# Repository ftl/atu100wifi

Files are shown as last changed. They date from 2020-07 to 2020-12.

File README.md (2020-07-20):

# atu100wifi

This is a little extension device for David Fainitski's [ATU-100](https://github.com/Dfinitski/N7DDC-ATU-100-mini-and-extended-boards) antenna tuner. It adds connectivity though wifi to use the tuner in a remote setup. The software publishes all measurement data using MQTT and accepts remote commands through another MQTT topic.

The device replaces the tuner's display. It communicates with the ATU-100 through it's I2C bus to grasp all the measurement data. An Arduino Nano acts as I2C slave, listening with the display's address, and interpreting the rendering commands coming from the ATU-100. The Nano sends the display content to an ESP8266 [WeMos D1 mini](https://www.wemos.cc/en/latest/d1/d1_mini.html), where the data is parsed, packed into a JSON object and published to a MQTT topic.

This project uses PlatformIO to build the software for the MCUs.

## Disclaimer
I develop this device for myself and just for fun in my free time. If you find it useful, I'm happy to hear about that. If you have trouble using it, you have all the source code to fix the problem yourself (although pull requests are welcome).

I am not liable for whatever happens to you by building or using this device. Do this on your own risk!

## License
This tool is published under the [MIT License](https://www.tldrlegal.com/l/mit).

Copyright [Florian Thienel](http://thecodingflow.com/)

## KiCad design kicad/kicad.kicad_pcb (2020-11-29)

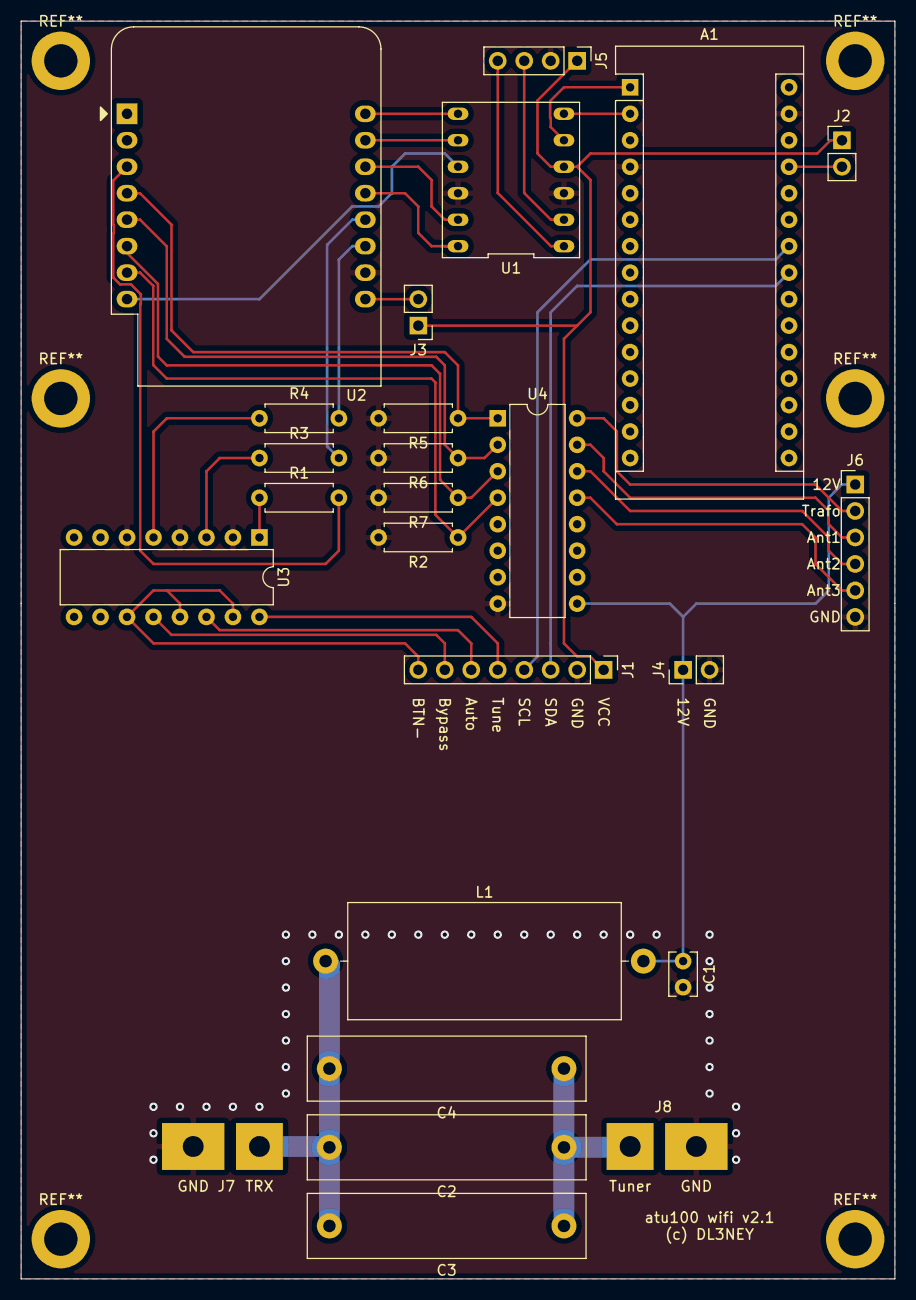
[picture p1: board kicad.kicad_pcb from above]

Board: 2 copper layers, 83.8 x 120.7 mm, 25 parts (0 on the bottom side), 36 nets.

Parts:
A1: Arduino_Nano_v3.x; Arduino_Nano
C1: 100n; C_Rect_L4.0mm_W2.5mm_P2.50mm
C2, C3, C4: 10n; C_Rect_L26.5mm_W6.0mm_P22.50mm_MKS4
J1: ATU100; PinHeader_1x08_P2.54mm_Vertical
J2, J3: Conn_01x02_Male; PinHeader_1x02_P2.54mm_Vertical
J4: ATU100_12V; PinHeader_1x02_P2.54mm_Vertical
J5: Display/I2C; PinHeader_1x04_P2.54mm_Vertical
J6: Ant Switch; PinHeader_1x06_P2.54mm_Vertical
J7: TRX; SolderWirePad_1x02_P7.62mm_Drill2mm
J8: Tuner; SolderWirePad_1x02_P7.62mm_Drill2mm
L1: 1m; L_Axial_L26.0mm_D11.0mm_P30.48mm_Horizontal_Fastron_77A
R1, R3, R4: 470; R_Axial_DIN0207_L6.3mm_D2.5mm_P7.62mm_Horizontal
R2, R5, R6, R7: 10k; R_Axial_DIN0207_L6.3mm_D2.5mm_P7.62mm_Horizontal
U1: 4Bit_China_Level_Shifter
U2: WeMos_D1_mini; WEMOS_D1_mini_light
U3: LTV-847; DIP-16_W7.62mm
U4: ULN2004A; DIP-16_W7.62mm

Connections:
+3V3: U1.9, U2.8
+12V: C1.1, J4.1, J6.1, L1.2, U4.9
Ant1: J6.3, U4.15
Ant2: J6.4, U4.14
Ant3: J6.5, U4.13
BTN-: J1.8, U3.11, U3.13, U3.15
BTNAuto+: J1.6, U3.14
BTNByp+: J1.7, U3.12
BTNTune+: J1.5, U3.16
D0: R1.2, U2.3
D1: U1.11, U2.14
D2: U1.12, U2.13
D3: R3.2, U2.12
D4: R4.2, U2.11
D5: R5.1, U2.4, U4.1
D6: R6.1, U2.5, U4.2
D7: R7.1, U2.6, U4.3
D8: R2.1, U2.7, U4.4
GND: A1.4, A1.29, C1.2, J1.2, J4.2, J5.2, J6.6, J7.2, J8.2, R2.2, R5.2, R6.2, R7.2, U1.3, U1.10, U2.10, U3.2, U3.4, U3.6, U4.8
unnamed: A1.1, U1.5
unnamed: A1.2, U1.6
unnamed: A1.27, J2.2
unnamed: C2.1, C3.1, C4.1, J8.1
unnamed: C2.2, C3.2, C4.2, J7.1, L1.1
unnamed: J3.2, U2.9
unnamed: R1.1, U3.1
unnamed: R3.1, U3.3
unnamed: R4.1, U3.5
unnamed: U1.7, U2.16
unnamed: U1.8, U2.15
SCL: A1.24, J1.4
SCL2: J5.4, U1.1
SDA: A1.23, J1.3
SDA2: J5.3, U1.2
Trafo: J6.2, U4.16
VCC: J1.1, J2.1, J3.1, J5.1, U1.4

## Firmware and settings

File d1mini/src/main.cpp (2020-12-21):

/*
  This piece of software receives the display content of the ATU-100 on the serial interface
  and publishes the measurement data via MQTT.

  The following topics are used to publish data:
  * MQTT_DATA_TOPIC: all the measurement data as JSON object, on every change
  * MQTT_RSSI_TOPIC: the current RSSI of the wifi, every 10 seconds
  * MQTT_WILL_TOPIC: "true" as soon as the MQTT connection is established, "false" as last will

  The software also subscribes to MQTT_CMD_TOPIC in order to receive commands:
  * "1" will push the TUNE button for 500ms
  * "2" will push the AUTO button for 500ms
  * "3" will push the BYPASS button for 500ms
  * "4" will turn on the TRAFO relay
  * "5" will turn off the TRAFO relay
  * "6" will turn on the ANT1 relay
  * "7" will turn on the ANT2 relay
  * "8" will turn on the ANT3 relay
  
  All configuration data is defined in the file include/config.h. Create it from include/config-template.
*/

#include <Arduino.h>
#include <ESP8266WiFi.h>
#include <WiFiClient.h>
#include <PubSubClient.h>
#include "config.h" // create this header from include/config-template.h and fill it with all your configuration data

#define TUNE_BTN D0
#define AUTO_BTN D3
#define BYPASS_BTN D4 // this is the LED_BUILTIN and we need it to indicate the status of the WIFI connection

#define TRAFO_RLY D5
#define ANT1_RLY D6
#define ANT2_RLY D7
#define ANT3_RLY D8

void onMQTTMessage(char*, byte*, unsigned int);

WiFiClient client;
WiFiClient wifi;
PubSubClient mqtt(wifi);
bool wifiConnected = false;
bool mqttConnected = false;

long lastBeat = 0L;

String displayContent;
uint8_t currentIndex = 0;

void handleDisplayUpdate();

void blinkLED(int on, int off) {
  #ifdef WIFI_LED
  digitalWrite(LED_BUILTIN, LOW);
  delay(on);
  digitalWrite(LED_BUILTIN, HIGH);
  delay(off);
  #endif
}

void publishString(String topic, String value) {
  char topicBuf[topic.length() + 1];
  topic.toCharArray(topicBuf, topic.length() + 1);

  char valueBuf[value.length() + 1];
  value.toCharArray(valueBuf, value.length() + 1);
    
  mqtt.publish(topicBuf, valueBuf, true);  
}

void publishInt(String topic, int value) {
  String str = String(value);
  publishString(topic, str);
}

void heartbeat(int seconds) {
  if (!mqtt.connected()) return;

  long now = millis();
  if (now - lastBeat < seconds * 1000) return;
  lastBeat = now;

  String rssi = String(WiFi.RSSI());

  publishString(MQTT_RSSI_TOPIC, rssi);
}

void setupOutput(uint8_t pin) {
  pinMode(pin, OUTPUT);
  digitalWrite(pin, LOW);
}

void setup() {
  pinMode(LED_BUILTIN, OUTPUT);
  setupOutput(TUNE_BTN);
  setupOutput(AUTO_BTN);
  setupOutput(TRAFO_RLY);
  setupOutput(ANT1_RLY);
  setupOutput(ANT2_RLY);
  setupOutput(ANT3_RLY);

  digitalWrite(ANT1_RLY, HIGH);

  Serial.begin(9600);
}

void loop() {
  if (WiFi.status() != WL_CONNECTED) {
    Serial.println("No WiFi connection");
    wifiConnected = false;
    WiFi.hostname(WIFI_HOSTNAME);
    WiFi.begin(WIFI_SSID, WIFI_PASSPHRASE);
    for (int i = 0; i < 10 && WiFi.status() != WL_CONNECTED; i++) {
      blinkLED(50, 450);
    }

    if (WiFi.status() == WL_CONNECTED) {
      Serial.println("WiFi connected");
      wifiConnected = true;
      mqtt.setServer(MQTT_HOST, MQTT_PORT);
    }
    return;
  }

  if (!mqttConnected) {
    Serial.println("No MQTT connection");
    blinkLED(50, 50);
    blinkLED(50, 350);
    mqtt.setCallback(onMQTTMessage);
    mqttConnected = mqtt.connect(MQTT_CLIENT_ID, MQTT_USER, MQTT_PASSWORD, MQTT_WILL_TOPIC, 2, true, "false");
    if (mqttConnected) {
      Serial.println("MQTT connected");
      publishString(MQTT_WILL_TOPIC, "true");
      mqtt.subscribe(MQTT_CMD_TOPIC);
    }
    return;
  }

  #ifdef WIFI_LED
  digitalWrite(LED_BUILTIN, LOW);
  #endif

  // handle the input from the Arduino Nano
  if (Serial.available()) {
      char c = Serial.read();
      if (c == 0x0A) {
          handleDisplayUpdate();
          currentIndex = 0;
          displayContent = "";
      } else if (c < 0x20) {
          // ignore control characters
      } else {
          displayContent += c;
      }
  }

  heartbeat(10);

  mqtt.loop();
}

void handleDisplayUpdate() {
  if (displayContent.substring(0, 4) != "PWR=") {
    Serial.println("wrong line format");
    return;
  }

  String pwrIn = displayContent.substring(4, 7);
  pwrIn.trim();
  bool autoMode = (displayContent.charAt(8) == '.');
  bool txing = (displayContent.charAt(11) == '=') || ((displayContent.charAt(76) == '='));
  bool tuning = displayContent.substring(68, 72) == "TUNE";
  bool resetting = displayContent.substring(64, 69) == "RESET";

  String swr = "";
  if (displayContent.substring(64, 68) == "SWR=" && !tuning) {
    swr = displayContent.substring(68, 72);
  }

  String pwrOut = "";
  String efficiency = "";
  bool lcNetwork = false;
  String inductance = "";
  String capacitance = "";
  if (txing) {
    pwrOut = displayContent.substring(12, 15);
    efficiency = displayContent.substring(77, 79);
  } else if (displayContent.charAt(9) == 'L') {
    lcNetwork = true;
    inductance = displayContent.substring(11, 15);
    capacitance = displayContent.substring(75, 79);
    capacitance.trim();
  } else {
    lcNetwork = false;
    inductance = displayContent.substring(75, 79);
    capacitance = displayContent.substring(11, 15);
    capacitance.trim();
  }

  String json = "{";
  if (tuning) {
    json += "\"tuning\":true,";
  } else {
    json += "\"tuning\":false,";
  }
  if (resetting) {
    json += "\"resetting\":true,";
  } else {
    json += "\"resetting\":false,";
  }
  if (autoMode) {
    json += "\"auto_mode\":true,";
  } else {
    json += "\"auto_mode\":false,";
  }
  json += "\"pwr_in\":" + pwrIn + ",";
  if (txing) {
    json += "\"txing\":true,";
    json += "\"pwr_out\":" + pwrOut + ",";
    json += "\"efficiency\":" + efficiency + ",";
  } else {
    json += "\"txing\":false,";
    json += "\"pwr_out\":0,";
    json += "\"efficiency\":0,";
  }
  if (swr != "") {
    json += "\"swr\":" + swr + ",";
  } else {
    json += "\"swr\":0,";
  }
  if (lcNetwork) {
    json += "\"lc_network\":true";
  } else {
    json += "\"lc_network\":false";
  }
  if (inductance != "" && capacitance != "") {
    json += ",\"inductance\":" + inductance + ",";
    json += "\"capacitance\":" + capacitance;
  }
  json += "}";

  publishString(MQTT_DATA_TOPIC, json);
}

void pressButton(uint8_t pin) {
  Serial.print("press button ");
  Serial.println(pin);
  digitalWrite(pin, HIGH);
  delay(500);
  digitalWrite(pin, LOW);
}

void switchTrafo(uint8_t val) {
  Serial.print("switch trafo ");
  Serial.println(val);
  digitalWrite(TRAFO_RLY, val);
  publishInt(MQTT_TRAFO_RELAY_TOPIC, val);
}

void selectAntenna(uint8_t antenna) {
  Serial.print("select antenna ");
  Serial.println(antenna);
  switch (antenna) {
  case 1:
    digitalWrite(ANT1_RLY, HIGH);
    digitalWrite(ANT2_RLY, LOW);
    digitalWrite(ANT3_RLY, LOW);
    break;
  case 2:
    digitalWrite(ANT1_RLY, LOW);
    digitalWrite(ANT2_RLY, HIGH);
    digitalWrite(ANT3_RLY, LOW);
    break;
  case 3:
    digitalWrite(ANT1_RLY, LOW);
    digitalWrite(ANT2_RLY, LOW);
    digitalWrite(ANT3_RLY, HIGH);
    break;
  default:
    antenna = 1;
    digitalWrite(ANT1_RLY, HIGH);
    digitalWrite(ANT2_RLY, LOW);
    digitalWrite(ANT3_RLY, LOW);
  }
  publishInt(MQTT_ANT1_RELAY_TOPIC, (antenna == 1));
  publishInt(MQTT_ANT2_RELAY_TOPIC, (antenna == 2));
  publishInt(MQTT_ANT3_RELAY_TOPIC, (antenna == 3));
}

void onMQTTMessage(char* topic, byte* payload, unsigned int length) {
  if (length == 0) {
    return;
  }
  char c = (char)payload[0];
  switch (c) {
  case '1':
    pressButton(TUNE_BTN);
    break;
  case '2':
    pressButton(TUNE_BTN);
    break;
  case '3':
    pressButton(TUNE_BTN);
    break;
  case '4':
    switchTrafo(HIGH);
    break;
  case '5':
    switchTrafo(LOW);
    break;
  case '6':
    selectAntenna(1);
    break;
  case '7':
    selectAntenna(2);
    break;
  case '8':
    selectAntenna(3);
    break;
  }
}

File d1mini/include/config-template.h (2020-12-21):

/*
    This header contains all the configuration data.
*/

#define WIFI_SSID "myssid"
#define WIFI_PASSPHRASE "mysecretpassphrase"
#define WIFI_HOSTNAME "myatu100"
// uncomment to use the built-in LED to indicate the WIFI status
// ATTENTION: this collides with the support for the BYPASS button. 
// If you use WIFI_LED, do NOT connect the BYPASS button!
// #define WIFI_LED

#define MQTT_HOST "192.168.1.1"
#define MQTT_PORT 1883
#define MQTT_CLIENT_ID "atu100"
#define MQTT_USER ""
#define MQTT_PASSWORD ""
#define MQTT_DATA_TOPIC "hamradio/atu100/data"
#define MQTT_RSSI_TOPIC "hamradio/atu100/rssi"
#define MQTT_WILL_TOPIC "hamradio/atu100/alive"
#define MQTT_CMD_TOPIC "hamradio/atu100/cmd"
#define MQTT_TRAFO_RELAY_TOPIC "afu/atu100/relays/trafo"
#define MQTT_ANT1_RELAY_TOPIC "afu/atu100/relays/ant1"
#define MQTT_ANT2_RELAY_TOPIC "afu/atu100/relays/ant2"
#define MQTT_ANT3_RELAY_TOPIC "afu/atu100/relays/ant3"

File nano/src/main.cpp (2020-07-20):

/*
  This piece of software acts as like a HD44780 LCD on the I2C bus. 
  
  The Nano receives the HD44780 instructions as an I2C slave using the default pins A4 (SDA) and A5 (SCL).
  It applies the instructions to a local representation of the display content. On each change
  of the display content it sends the whole display content (80 characters) out via the serial interface (TX pin).

  More details about the HD44780 LCD instruction set: 
  * https://mil.ufl.edu/3744/docs/lcdmanual/commands.html
  * https://www.sparkfun.com/datasheets/LCD/HD44780.pdf

  Only instructions that affect the display content are implemented (no read, no character generation).
*/

#include <Arduino.h>
#include <Wire.h>

#define LCD_ADDRESS 0x27
#define LCD_LENGTH 80
#define DDRAM 0
#define CGRAM 1
#define PUBLISH_THRESHOLD 100

bool dirty = false;
unsigned long cleanTime = 0;
bool published = true;

char ddram[LCD_LENGTH];
bool ramIndex = DDRAM;
uint8_t currentAddress = 0;
bool entryModeIncrement = true;
bool entryModeShift = false;

void onReceive(int);
void handleCommand(bool, bool, uint8_t);
void clearDisplay();
void cursorHome();
void setEntryMode(bool, bool);
void setOnOff(bool, bool, bool);
void setShift(bool, bool);
void setFunction(bool, bool, bool);
void setCGAddress(uint8_t);
void setDDAddress(uint8_t);
void writeData(char);

void setup() {
    pinMode(LED_BUILTIN, OUTPUT);

    Wire.begin(LCD_ADDRESS);
    Wire.onReceive(onReceive);

    Serial.begin(9600);

    for (int i = 0; i < LCD_LENGTH; i+=1) {
      ddram[i] = 0x20;
    }
}

void loop() {
  if (dirty) {
    dirty = false;
    published = false;
    cleanTime = millis();
  } else if ((millis() - cleanTime > PUBLISH_THRESHOLD) && !published) {
    for (int i = 0; i < LCD_LENGTH; i+=1) {
      Serial.write(ddram[i]);
    }
    Serial.println();
    published = true;
  }
  delay(1);
}

bool nibbleIndex = 0;
uint8_t loNibble = 0;
uint8_t hiNibble = 0;

void onReceive(int count) {
  digitalWrite(LED_BUILTIN, LOW);
  while(Wire.available()) {
    uint8_t in = Wire.read();
    bool enable = in & 0x04;
    if (!enable) {
      continue;
    }

    if (nibbleIndex) {
      loNibble = in;

      bool rs = loNibble & 0x01;
      bool rw = loNibble & 0x02;
      uint8_t cmd = (hiNibble & 0xF0) | ((loNibble & 0xF0) >> 4);

      handleCommand(rs, rw, cmd);
    } else {
      loNibble = 0;
      hiNibble = in;
    }
    nibbleIndex = !nibbleIndex;
  }
  digitalWrite(LED_BUILTIN, HIGH);
}

void handleCommand(bool rs, bool rw, uint8_t cmd) {
  if (rw) {
    Serial.println("read not implemented");
    return;
  }

  if (rs) {
    writeData(cmd);
    return;
  }

  if (cmd == 0x01) {
    clearDisplay();
  } else if ((cmd & 0xFE) == 0x02) {
    cursorHome();
  } else if ((cmd & 0xFC) == 0x04) {
    bool increment = (cmd & 0x02);
    bool shift = (cmd & 0x01);
    setEntryMode(increment, shift);
  } else if ((cmd & 0xF8) == 0x08) {
    bool display = (cmd & 0x04);
    bool cursor = (cmd & 0x02);
    bool blink = (cmd & 0x01);
    setOnOff(display, cursor, blink);
  } else if ((cmd & 0xF0) == 0x10) {
    bool display = (cmd & 0x08);
    bool right = (cmd & 0x04);
    setShift(display, right);
  } else if ((cmd & 0xE0) == 0x20) {
    bool full = (cmd & 0x10);
    bool twoLines = (cmd & 0x08);
    bool bigFont = (cmd & 0x04);
    setFunction(full, twoLines, bigFont);
  } else if ((cmd & 0xC0) == 0x40) {
    uint8_t address = (cmd & 0x3F);
    setCGAddress(address);
  } else if ((cmd & 0x80) == 0x80) {
    uint8_t address = (cmd & 0x7F);
    setDDAddress(address);
  } 
}

void clearDisplay() {
  // https://mil.ufl.edu/3744/docs/lcdmanual/commands.html#ClearDisplay
  for (int i = 0; i < LCD_LENGTH; i+=1) {
    ddram[i] = 0x20;
  }
  dirty = true;
  currentAddress = 0;
  entryModeIncrement = true;

}

void cursorHome() {
  // https://mil.ufl.edu/3744/docs/lcdmanual/commands.html#CursorHome
  currentAddress = 0;
}

void setEntryMode(bool increment, bool shift) {
  // https://mil.ufl.edu/3744/docs/lcdmanual/commands.html#EntryMode
  entryModeIncrement = increment;
  entryModeShift = shift;
}

void setOnOff(bool display, bool cursor, bool blink) {
  // https://mil.ufl.edu/3744/docs/lcdmanual/commands.html#Doo
  // not relevant for the display content
}

void setShift(bool display, bool right) {
  // https://mil.ufl.edu/3744/docs/lcdmanual/commands.html#Cds
  if (right) {
    currentAddress = (currentAddress + 1) % LCD_LENGTH;
  } else if (currentAddress > 0) {
    currentAddress -= 1;
  } else {
    currentAddress = LCD_LENGTH - 1;
  }
}

void setFunction(bool full, bool twoLines, bool bigFont) {
  // https://mil.ufl.edu/3744/docs/lcdmanual/commands.html#Fs
  // not relevant for the display content
}

void setCGAddress(uint8_t address) {
  // https://mil.ufl.edu/3744/docs/lcdmanual/commands.html#Sca
  ramIndex = CGRAM;
}

void setDDAddress(uint8_t address) {
  // https://mil.ufl.edu/3744/docs/lcdmanual/commands.html#Sda
  ramIndex = DDRAM;
  currentAddress = address % LCD_LENGTH;
}

void writeData(char data) {
  // https://mil.ufl.edu/3744/docs/lcdmanual/commands.html#Wr
  if (ramIndex == CGRAM) {
    return;
  }

  ddram[currentAddress] = data;
  dirty = true;

  if (entryModeIncrement) {
    currentAddress = (currentAddress + 1) % LCD_LENGTH;
  }
}

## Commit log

2020-08-07 make thicker wires to make soldering of routed pcbs easier
    [kicad.kicad_pcb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]
2020-11-17 add output to switch an external relay with an external voltage
    [kicad.kicad_pcb, kicad.sch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]
2020-11-23 first attempt to leverage all IOs in order to support all three possible buttons and an external antenna switch
    [kicad.kicad_pcb, kicad.sch]
2020-11-29 move the 12V connector for the atu100 next to the control signal connector
    [kicad.kicad_pcb]
2020-12-21 use the ULN2003, stupid
    [kicad.sch]
2020-12-21 add support for one trafo and three antenna relays
